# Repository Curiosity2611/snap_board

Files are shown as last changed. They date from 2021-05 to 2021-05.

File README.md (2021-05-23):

## About the project

### Problem

Recently I came accross the ST's line of Microprocessors and I felt it fascinating. I personally felt this is one of the best Microprocessor out there in the market as it is the combination of an MPU and an  MCU. This combination has many use cases and I felt I should try this out. So I bought STM32MP157C-DK2 development board and started experimenting! <br>

Previously I had little experience working on couple of popular linux dev boards like the BeagleBone Black
and the Raspberry Pi. They are both fantastic boards to work with and they both have good community support. But while working with them, I realised a few bunch of problems:

- **Raspberry Pi Compute Module 4 + IO Board**
    - CM4 is easy to use but not ideal for mass production.
    - No support for analog signals at hardware level.
    - Software PWM possible but not very precise.
    - Cannot support real time application or processing.
    - Not fully open-source and very minimum customization possible. <br>
<br>

- **BeagleBone Black**
    - Easy to use but user has to own build hardware for production.
    - PRUs make RT applications possible but super difficult to use.
    - Cannot support MIPI-DSI and HD graphics.
    - Programming PRUs is not an easy task.

### Solution

**Best of both worlds**

**Hello World STM32MP1 !!**

- Board design inspired from Raspberry Pi Compute Module 4 and CM4 IO board.
- Operating system derived from Beaglebone Black with implementation of Bonescript Library and Cloud9 IDE.
- Footprint compatible Single or dual Cortex-A7 Processors + dedicated Cortex-M4 core for real-time and low-power applications.
- Support for MIPI-DSI display for HMI applications.
- Fully open-source Hardware and Software.

## Full Documentation

The full documentation is done using mkdocs tool and is present in the documentation folder. To view the doucmentation:
- Install mkdocs tool in your system.
- `cd` to `documentation/snap_board`
- run the command `mkdocs serve`
- Redirect your browser to `http://127.0.0.1:8000/`

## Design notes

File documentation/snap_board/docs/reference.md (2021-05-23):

# References for STM32MP157C

## Websites
- [STM32MP157C-DK2 official website](https://www.st.com/en/evaluation-tools/stm32mp157c-dk2.html#overview)
- [STM32MP157C Chipset](https://www.st.com/en/microcontrollers-microprocessors/stm32mp157c.html)

## Docs
- STM32MP157C-DK2 Development Board:

    - [Data Brief (PDF)](https://www.st.com/resource/en/data_brief/stm32mp157c-dk2.pdf)
    - [User Manual UM2534 (PDF)](https://www.st.com/resource/en/user_manual/dm00591354-discovery-kits-with-stm32mp157-mpus-stmicroelectronics.pdf)

- MPU:
    - [STM32MP157C DataSheet DS12505(PDF)](https://www.st.com/resource/en/datasheet/stm32mp157c.pdf)
    - [Reference Manual RM0436 (PDF)](https://www.st.com/resource/en/reference_manual/dm00327659-stm32mp157-advanced-armbased-32bit-mpus-stmicroelectronics.pdf)

- PMIC:
    - [STPMIC1 Datasheet (PDF)](https://www.mouser.in/datasheet/2/389/dm00551687-1799430.pdf)

- DDR3L:
    - [AS4C256M16D3LC-12BCN Datasheet (PDF)](https://www.mouser.in/datasheet/2/12/AllianceMemory_4G_DDR3L_AS4C256M16D3LC_March2020_R-1826861.pdf)

- eMMC:
    - [S40FC004C1B2C00000 Datasheet (PDF)](https://www.mouser.in/datasheet/2/980/SkyHigh_Memory_4GB_153_ball_VFBGA_eMMC_5.1_Data_Sh-1812167.pdf)

## CAD
- Board Manufacturing:

    - [Board Design Project Files 1.0 MB1272](https://www.st.com/resource/en/board_manufacturing_specification/mb1272_bdp.zip)
    - [Board Manufacturing Files 1.0 MB1272](https://www.st.com/resource/en/board_manufacturing_specification/mb1272_manufacturing.zip)

- Bill of Materials:

    - [BOM MB1272](https://www.st.com/resource/en/bill_of_materials/mb1272_bom.zip)
- Schematics:
    - [Schematic MB1272 (PDF)](https://www.st.com/resource/en/schematic_pack/mb1272-dk2-c01_schematic.pdf)

## Application Notes

- [Getting started with STM32MP15x Hardware Development AN5031](https://www.st.com/resource/en/application_note/dm00389996-getting-started-with-stm32mp151-stm32mp153-and-stm32mp157-line-hardware-development-stmicroelectronics.pdf)
- [STM31MP1 series DDR Memory routing guidelines AN5122](https://www.st.com/resource/en/application_note/dm00462392-stm32mp1-series-ddr-memory-routing-guidelines-stmicroelectronics.pdf)
- [Oscillator design guide for STM32MP15x AN2867](https://www.st.com/resource/en/application_note/cd00221665-oscillator-design-guide-for-stm8afals-stm32-mcus-and-mpus-stmicroelectronics.pdf)
- [Discrete Power supply hardware integration AN5256](https://www.st.com/resource/en/application_note/dm00561921-stm32mp151-stm32mp153-and-stm32mp157-discrete-power-supply-hardware-integration-stmicroelectronics.pdf)
- [USB-C power delivery AN5225](https://www.st.com/resource/en/application_note/dm00536349-usb-typec-power-delivery-using-stm32-mcus-and-mpus-stmicroelectronics.pdf)

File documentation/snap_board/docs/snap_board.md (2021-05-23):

## Hardware Development

### Introduction

Minimum hardware resources and recommendations provided by ST on how to use STM32MP151, STM32MP153 and STM32MP157 lines of MPUs. Refer Application note [Getting started with STM32MP15x Hardware Development AN5031](https://www.st.com/resource/en/application_note/dm00389996-getting-started-with-stm32mp151-stm32mp153-and-stm32mp157-line-hardware-development-stmicroelectronics.pdf) for more detailed information.

### Package Selection

A package is selected by taking into account the following constraints:

- Amount of interfaces required as some interfaces might not be available on some packages and some interfaces combinations might not be possible on some packages.
- PCB available area and PCB technology constraints. Small pitch and high ball density could require more PCB layers and higher PCB class requiring stackup with micro-via (laser via) technology.
- Package size and ball pitch.
- Cost of the MPU.

**Manufacturer Part Number** - STM32MP157CAC3 / STM32MP151CAC3 <br>
**Package** -  TFBGA361 <br>
**Package Size** - 12mm x 12mm. <br>
**Minimum Pitch** - 0.5mm (Center 0.65) <br>
**Thickness** - < 1.2mm. <br>
**Ball Count** - 361 <br>

### Power Supplies

#### General

The system is supplied with 12V DC power supply through a barrel jack connector present on the IO board. This 12V is step down to 5V using a buck converter on the I/O board and is supplied to the PMIC. <br>

**Schematic Name Tag for 5V supply** - `5V_VIN` <br>

#### ST PMIC Overview

**Manfacturer Part Number** - STPMIC1BPQR <br>
**Package** - WFQFN 44L <br>
**Package Dimesion** - 5mm x 6mm x 0.8mm <br>

!!! note
    The STPMIC1A and STPMIC1B are pre-programmed devices to support the STM32MP1 series application processor versions. 

The STPMIC1 provides all regulators needed to power supply a complete application. This IC is preset on Snap board. It has:

- 6 LDOs + 1 reference voltage LDO for DDR Memories. 
- 4 Step down (buck) converter. 
- 1 step-up(boost) converter with a bypass to supply USB sub-system.
- 2 power switches to supply USB sub-system. 

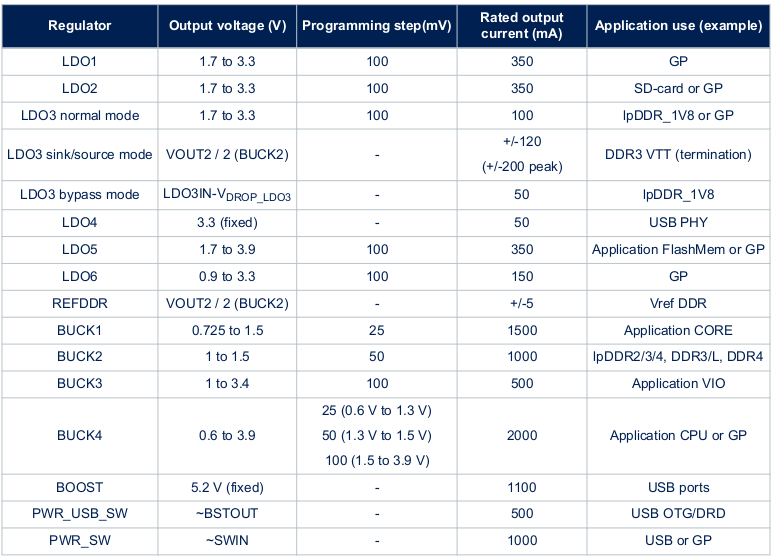
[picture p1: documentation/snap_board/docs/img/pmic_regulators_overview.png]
PMIC regulators overview


**LDO1, LDO2, LDO5, LDO6** are general purpose (GP) LDO (low-dropout) linear regulators and can be used to supply application peripherals. <br>

**LDO3** is a multipurpose linear regulator that supports 3 modes:

- **Normal mode**: operates as standard LDO with 1.7 to 3.3 V output voltage range (for general purpose use)
- **Sink/source mode**: LDO3 operates in sink/source regulation mode to supply termination resistors of DDR3/DDR3L memory interface (VTT voltage).
- **Bypass mode**: LDO3 operates as a simple power switch to supply lpDDR2/3 VDD1 (1.8 V) power domain. In that case, LDO3IN is supplied by 1.8 V. This is a preferred mode versus normal mode in term of power efficiency to power supply lpDDR2/3 VDD1.

!!! note
    In this application LDO3 is used as Sink/Source mode.

**LDO4** is a fixed output voltage (3.3 V) LDO and it is dedicated to power supply host processor USB PHY. <br>

**DDR REF** is sink/source reference voltage LDO dedicated to power VREF of lpDDR/DDR.<br>

**BOOST** is a fixed output voltage 5.2 V synchronous step-up converter dedicated to power supply USB ports (PWR_USB_SW and/or PWR_SW power switches).

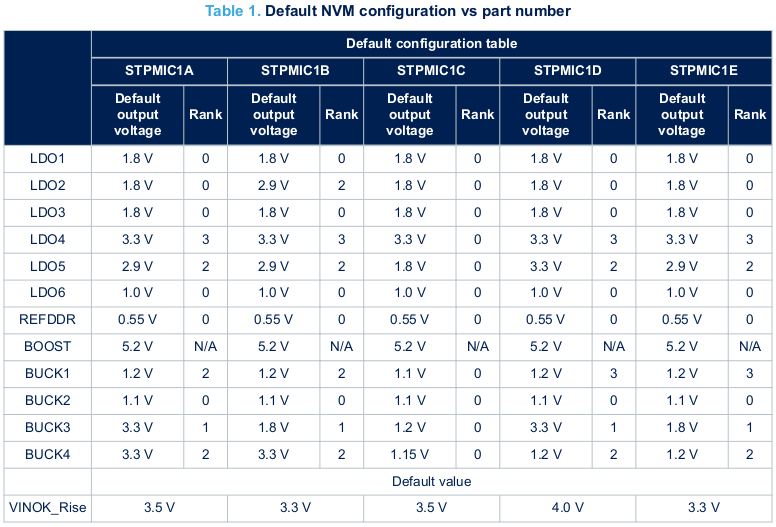
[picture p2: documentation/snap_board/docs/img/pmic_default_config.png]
PMIC Default Configuration


#### LDO Typical Schematic

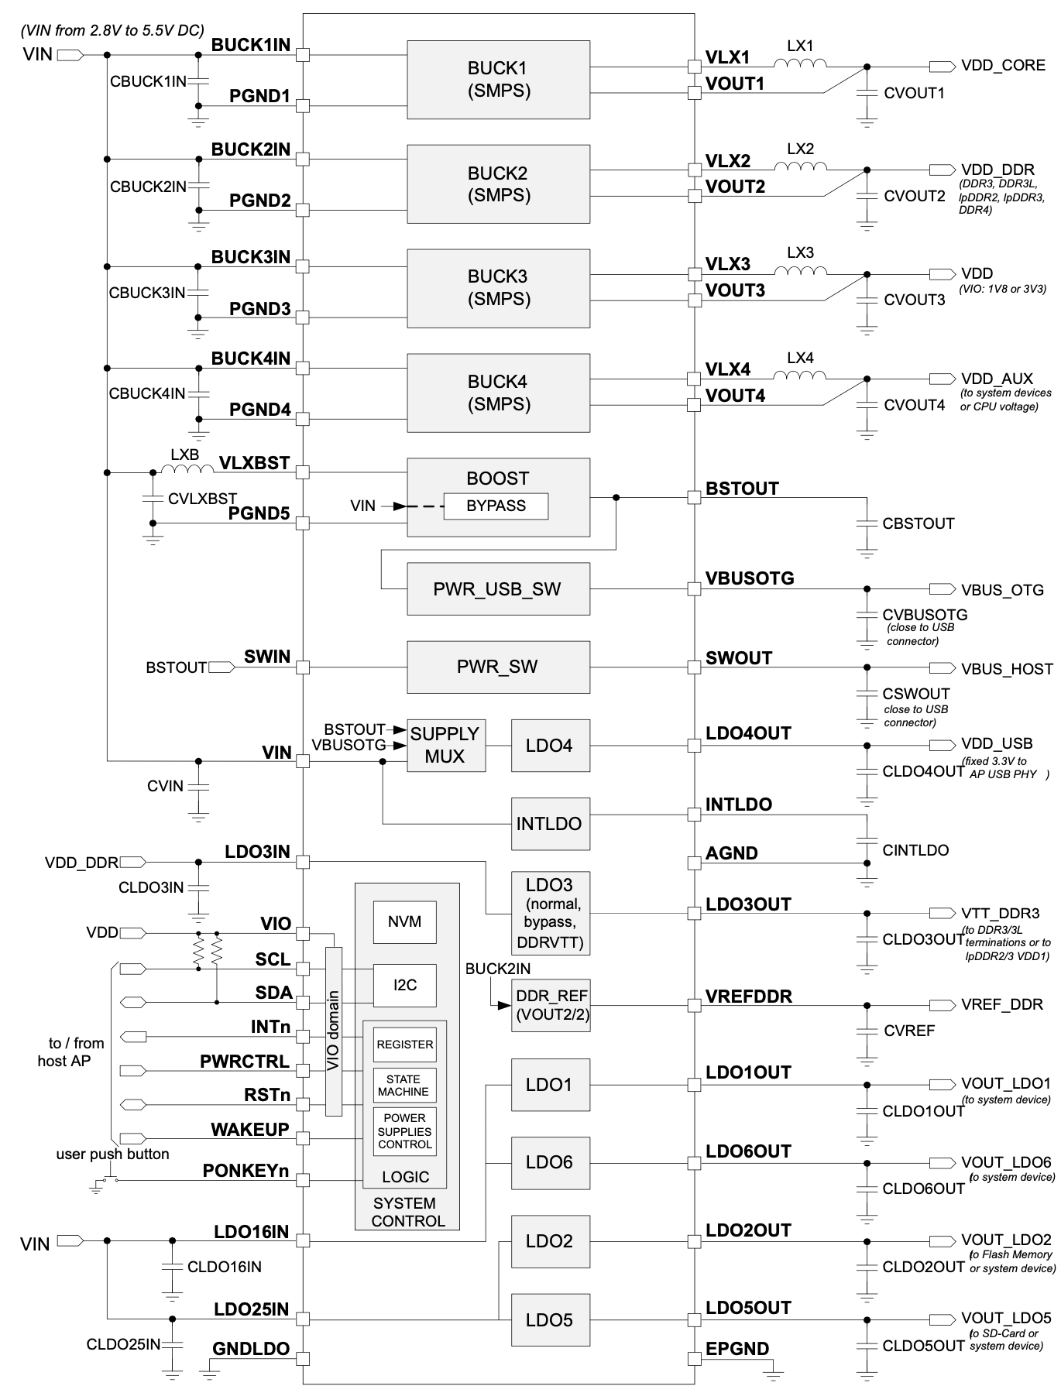
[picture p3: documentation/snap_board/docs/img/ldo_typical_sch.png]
Typical LDO Schematic


#### Powering DDR3 Memory with STPMIC

In this project, DDR3L memory is used. 

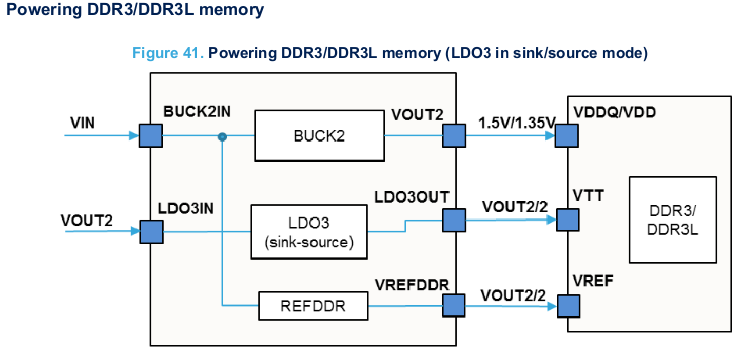
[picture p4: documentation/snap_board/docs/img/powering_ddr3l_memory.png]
Powering DDR3L Memory


LDO3IN is a power supply from BUCK2 output (VOUT2) and LDO3 output regulate at Vout2/2 voltage.

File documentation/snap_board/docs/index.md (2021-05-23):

# The Snap Project

### Problem

Recently I came accross the ST's line of Microprocessors and I felt it fascinating. I personally felt this is one of the best Microprocessor out there in the market as it is the combination of an MPU and an  MCU. This combination has many use cases and I felt I should try this out. So I bought STM32MP157C-DK2 development board and started experimenting! <br>

Previously I had little experience working on couple of popular linux dev boards like the BeagleBone Black
and the Raspberry Pi. They are both fantastic boards to work with and they both have good community support. But while working with them, I realised a few bunch of problems:

- **Raspberry Pi Compute Module 4 + IO Board**
    - CM4 is easy to use but not ideal for mass production.
    - No support for analog signals at hardware level.
    - Software PWM possible but not very precise.
    - Cannot support real time application or processing.
    - Not fully open-source and very minimum customization possible. <br>
<br>

- **BeagleBone Black**
    - Easy to use but user has to own build hardware for production.
    - PRUs make RT applications possible but super difficult to use.
    - Cannot support MIPI-DSI and HD graphics.
    - Programming PRUs is not an easy task.

### Solution

**Best of both worlds**

**Hello World STM32MP1 !!**

- Board design inspired from Raspberry Pi Compute Module 4 and CM4 IO board.
- Operating system derived from Beaglebone Black with implementation of Bonescript Library and Cloud9 IDE.
- Footprint compatible Single or dual Cortex-A7 Processors + dedicated Cortex-M4 core for real-time and low-power applications.
- Support for MIPI-DSI display for HMI applications.
- Fully open-source Hardware and Software.

This documentation is on design notes/decisions used to develop snap developement boards. This documentation will be updated from time to time based on new learnings and as the project progresses. This Wiki is designed to consolidate my knowledge into a one stop source for future refereces. That said, this Wiki is:

- Not exhaustive. 
- Constantly being updated with new information. 
- May contain some errors (will be corrected if found!)

### About Me!

My name is Deepak Reddy and I maintain this documentation. I hold an undergraduate degree in Electrical and Electronics Engineering and I worked as a Hardware Design Engineer for 4 years in a startup. During my time in the company, I developed various products that went from concept to production. I have designed PCBs arounds various SoCs such as 8-bit MCUs, and 32-bit MCUs. I have also designed rigid-flex and HDI PCBs.

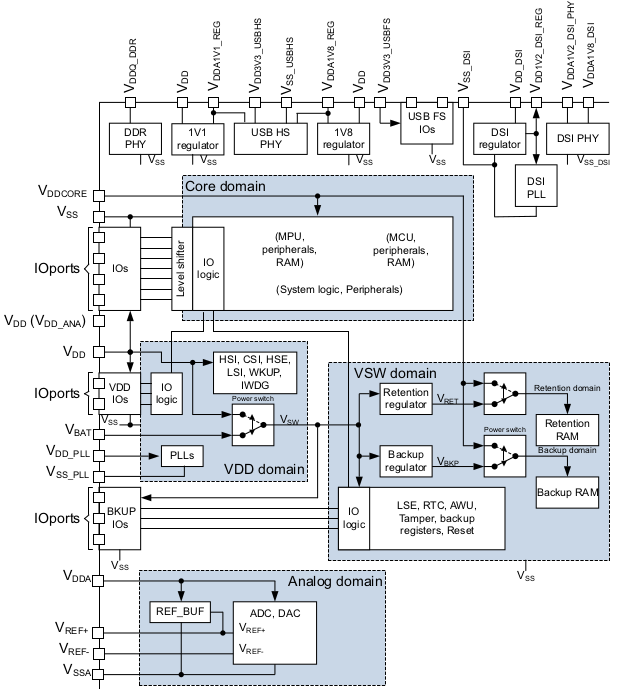
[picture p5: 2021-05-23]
documentation/snap_board/docs/img/power_supply_scheme.png

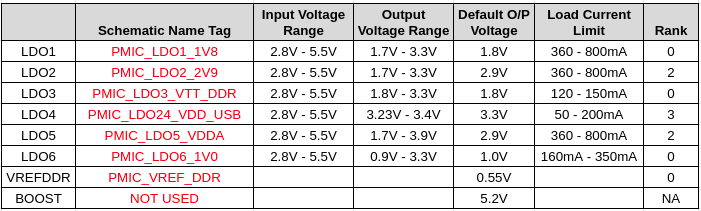
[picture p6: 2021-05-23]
documentation/snap_board/docs/img/ldo_voltages.png

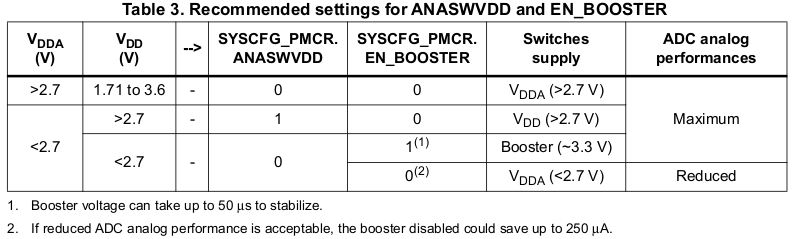
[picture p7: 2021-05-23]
documentation/snap_board/docs/img/ADC_SYSCFG_settings.png

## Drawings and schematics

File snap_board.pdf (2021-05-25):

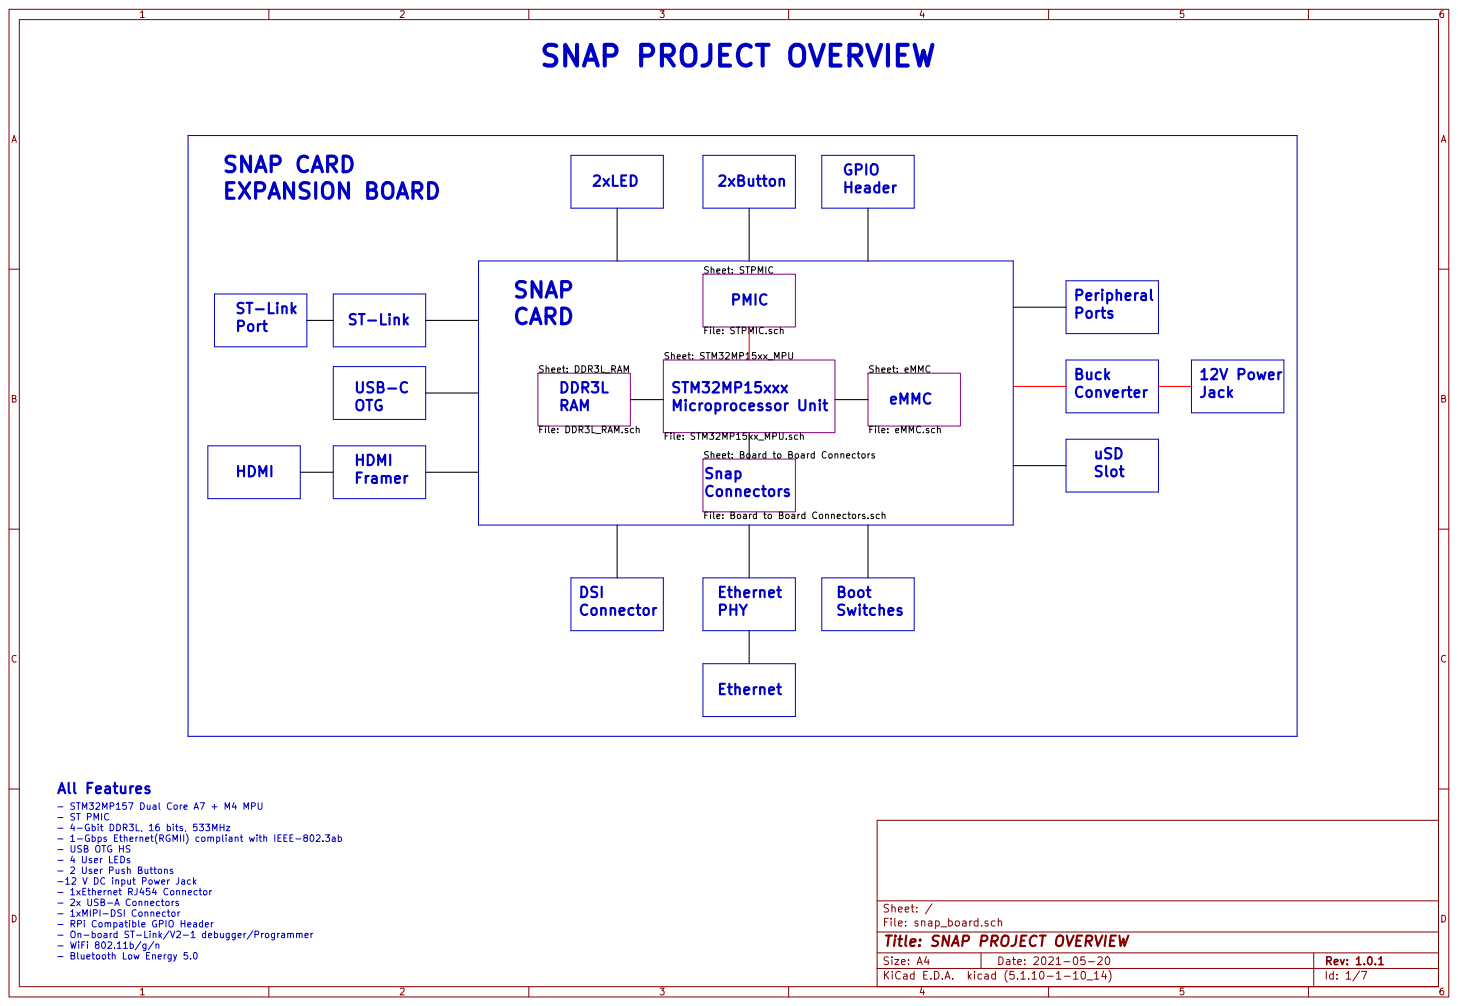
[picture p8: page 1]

Sheet: Board to Board Connectors File: Board to Board Connectors.sch Sheet: STPMIC
PMIC

- STM32MP157 Dual Core A7 + M4 MPU
- ST PMIC
- 4-Gbit DDR3L, 16 bits, 533MHz
- 1-Gbps Ethernet(RGMII) compliant with IEEE-802.3ab
- USB OTG HS
- 4 User LEDs
- 2 User Push Buttons
-12 V DC input Power Jack
- 1xEthernet RJ454 Connector
- 2x USB-A Connectors
- 1xMIPI-DSI Connector
- RPi Compatible GPIO Header
- On-board ST-Link/V2-1 debugger/Programmer
- WiFi 802.11b/g/n
- Bluetooth Low Energy 5.0

File: snap_board.sch Sheet: /
Id: 1/7 Title: SNAP PROJECT OVERVIEW

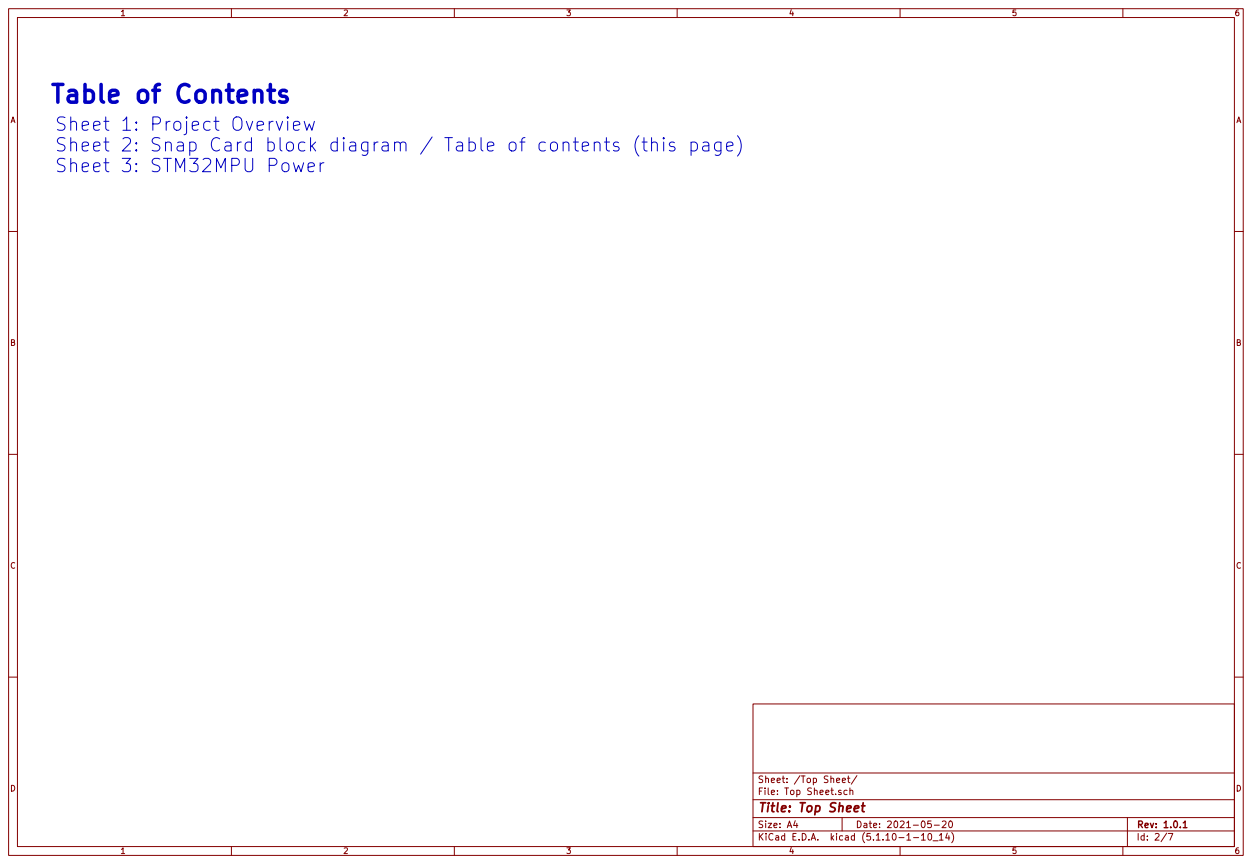
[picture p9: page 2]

Table of Contents
Sheet 1: Project Overview
Sheet 2: Snap Card block diagram / Table of contents (this page)
Sheet 3: STM32MPU Power

Sheet: /Top Sheet/
File: Top Sheet.sch
Id: 2/7 Title: Top Sheet

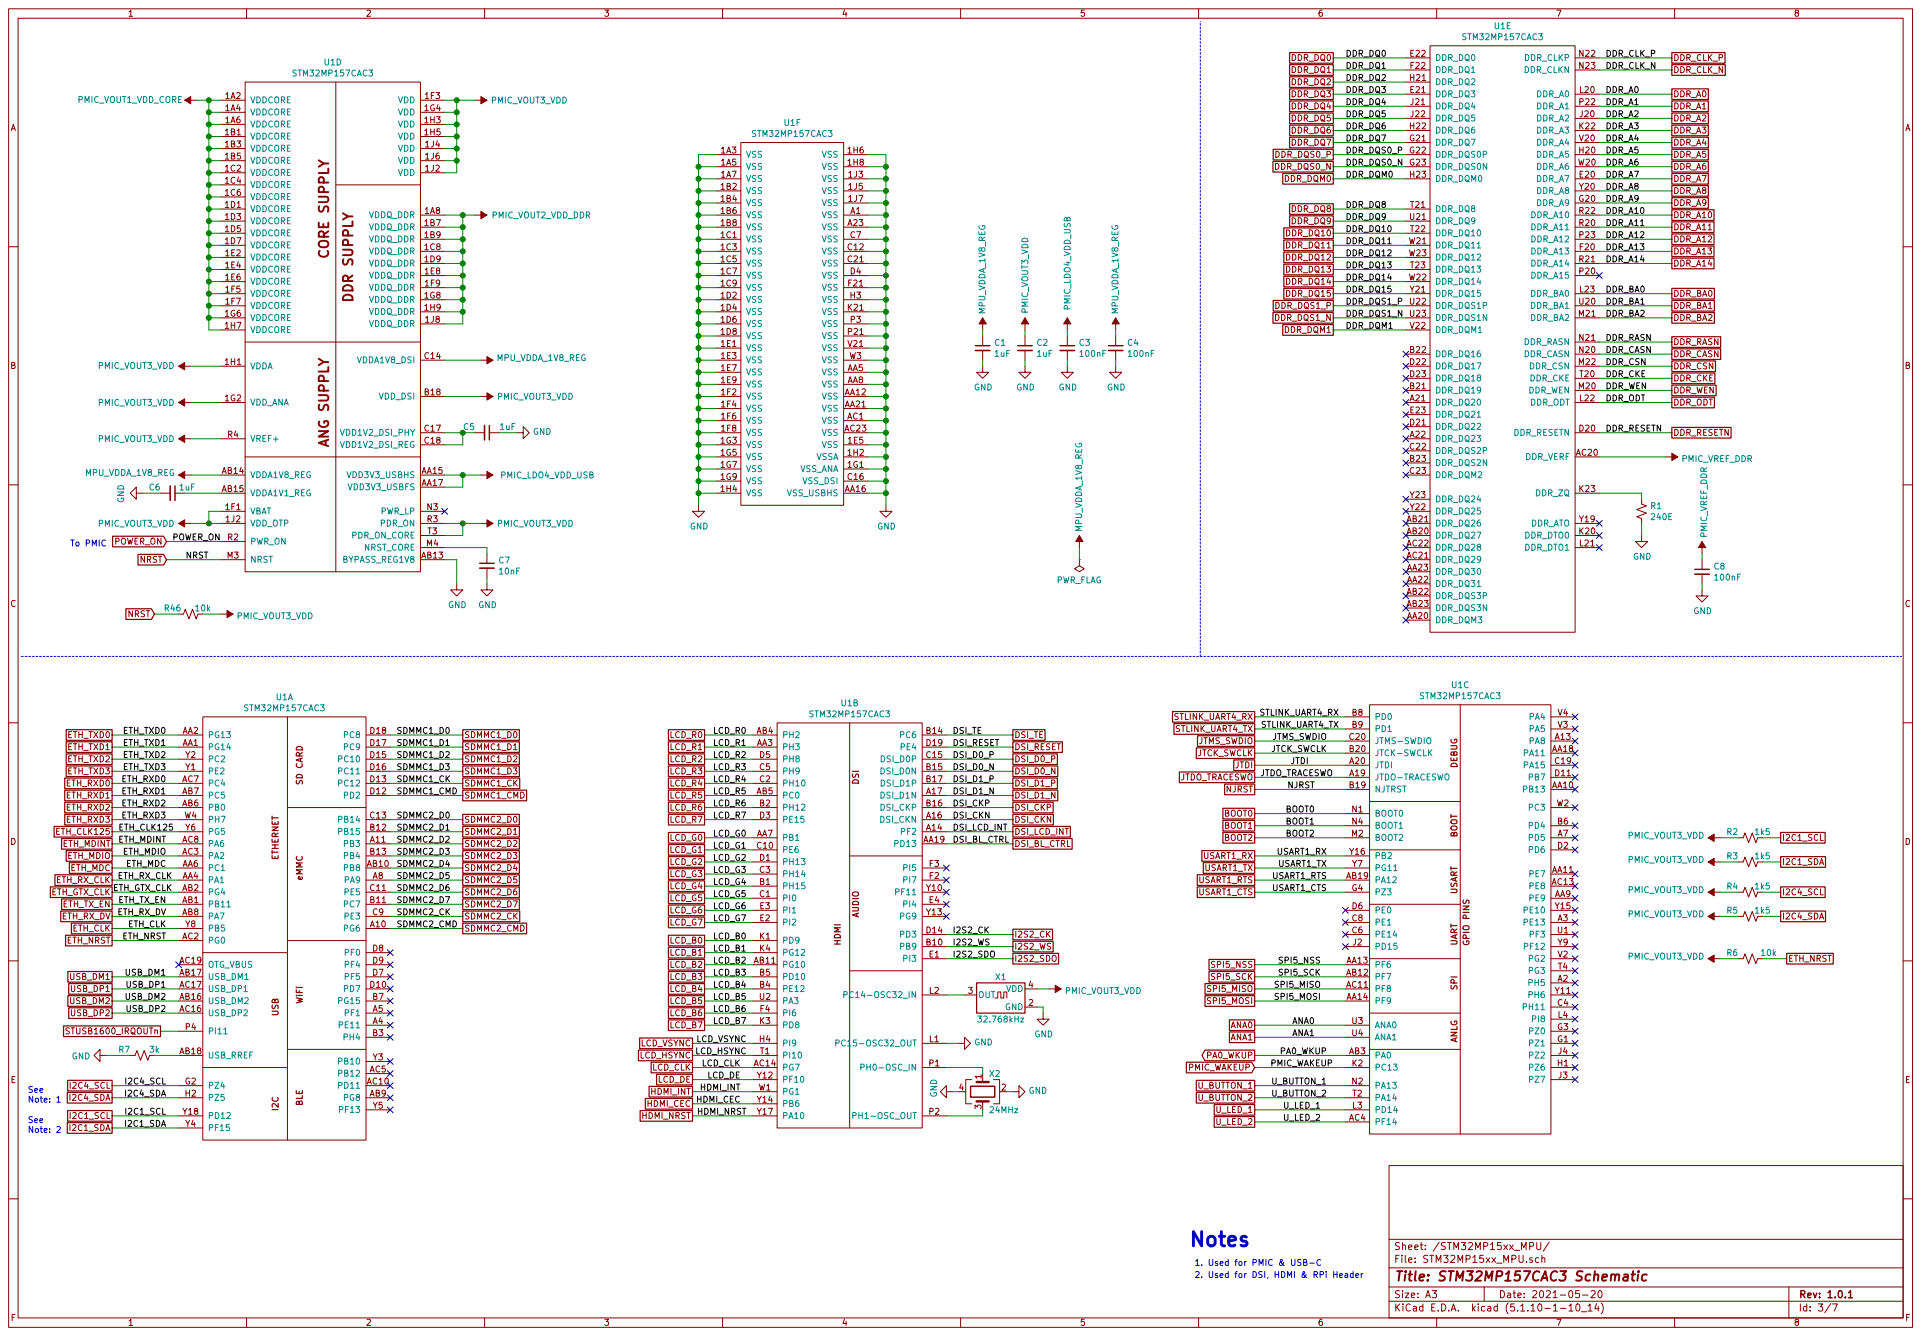
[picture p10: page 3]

ETH_RXD3 ETH_CLK125 ETH_RXD2 ETH_TXD3 ETH_RXD0 ETH_RXD1 See Note: 1 See Note: 2

1. Used for PMIC & USB-C
2. Used for DSI, HDMI & RPi Header

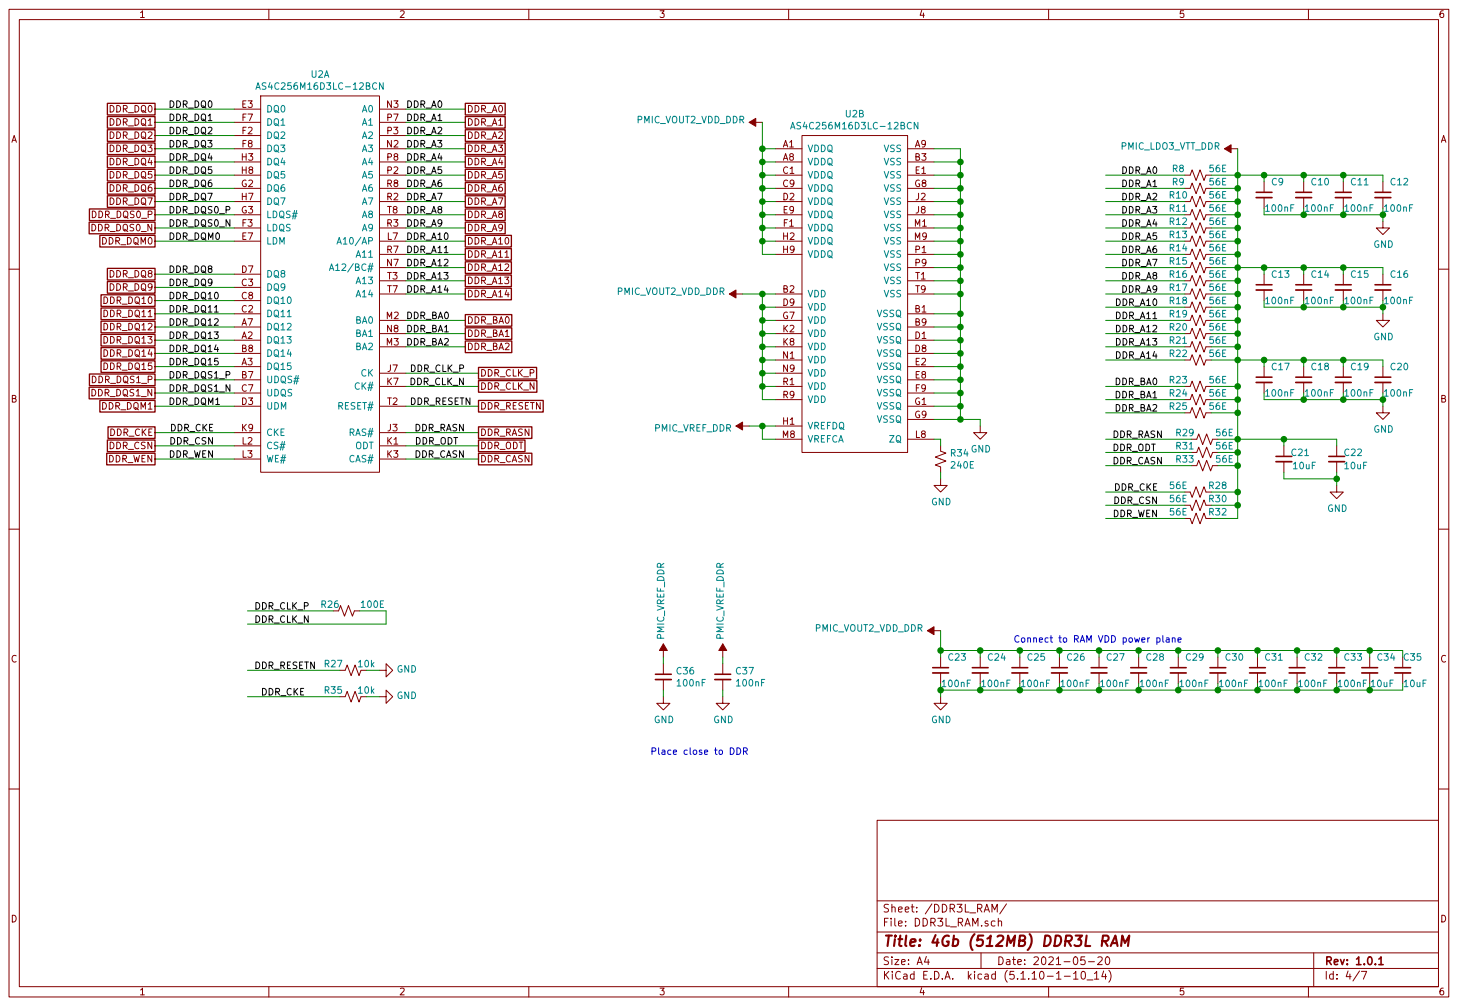
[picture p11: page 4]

DDR_CKE DDR_A2 DDR_A3 DDR_A4 DDR_A5 DDR_A6 DDR_A7 DDR_A8 DDR_A9 DDR_A10 DDR_A11 DDR_A12 DDR_A13 DDR_A14 DDR_BA0 Connect to RAM VDD power plane Place close to DDR

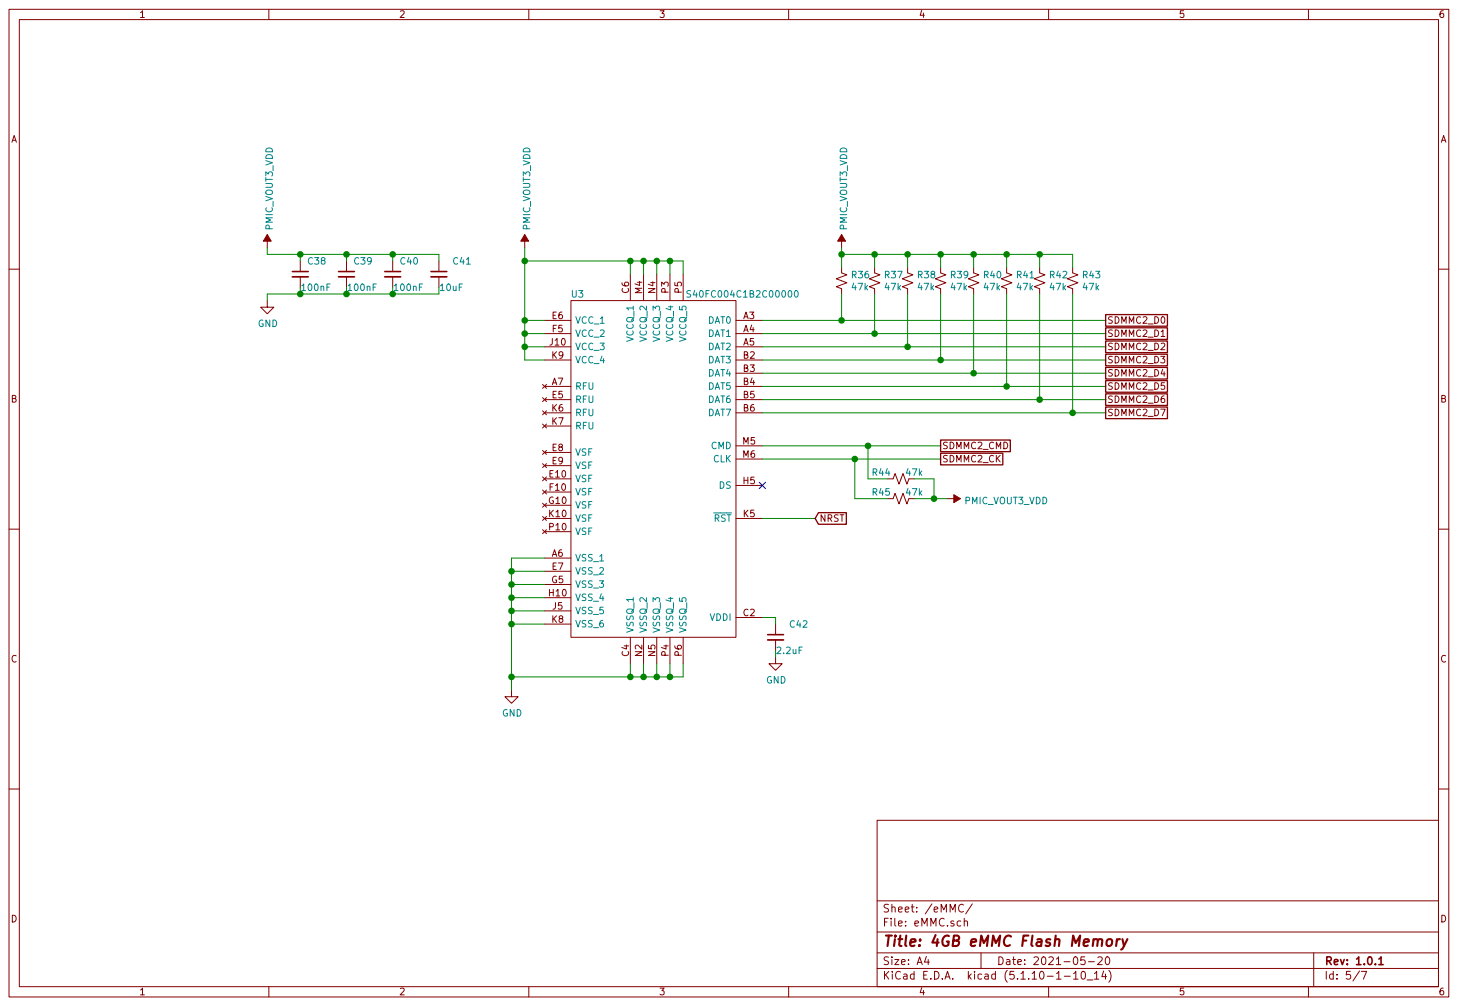
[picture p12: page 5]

Id: 5/7 Title: 4GB eMMC Flash Memory

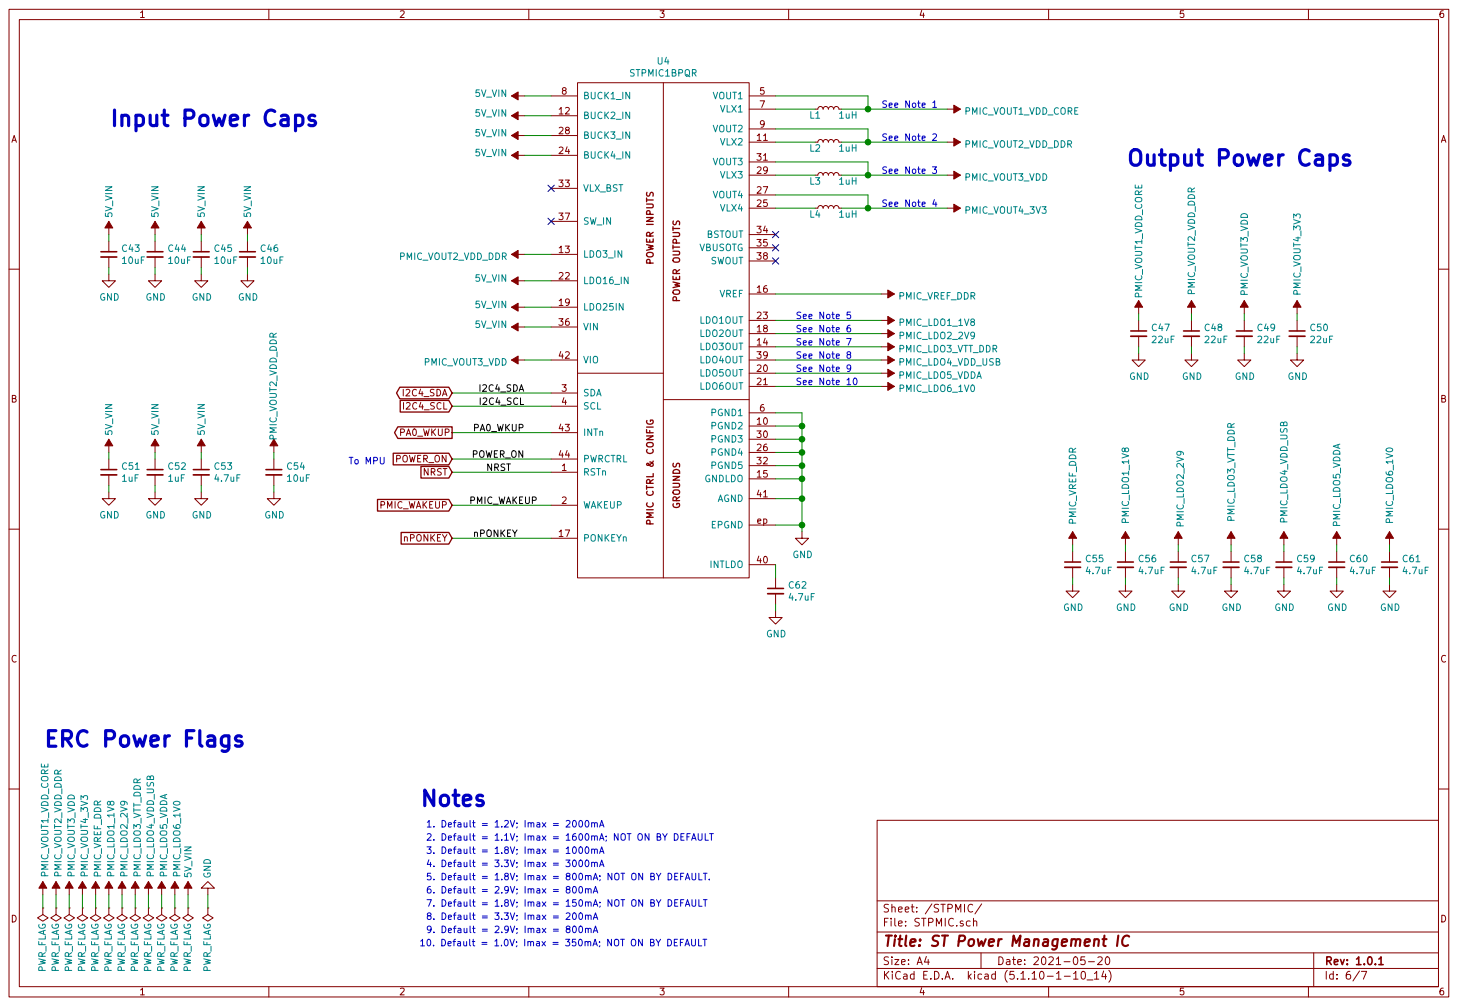
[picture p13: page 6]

4. Default = 3.3V; Imax = 3000mA ERC Power Flags

5. Default = 1.8V; Imax = 800mA; NOT ON BY DEFAULT. Notes

1. Default = 1.2V; Imax = 2000mA
2. Default = 1.1V; Imax = 1600mA; NOT ON BY DEFAULT
3. Default = 1.8V; Imax = 1000mA

6. Default = 2.9V; Imax = 800mA
7. Default = 1.8V; Imax = 150mA; NOT ON BY DEFAULT
8. Default = 3.3V; Imax = 200mA
9. Default = 2.9V; Imax = 800mA
10. Default = 1.0V; Imax = 350mA; NOT ON BY DEFAULT

Id: 6/7 Title: ST Power Management IC

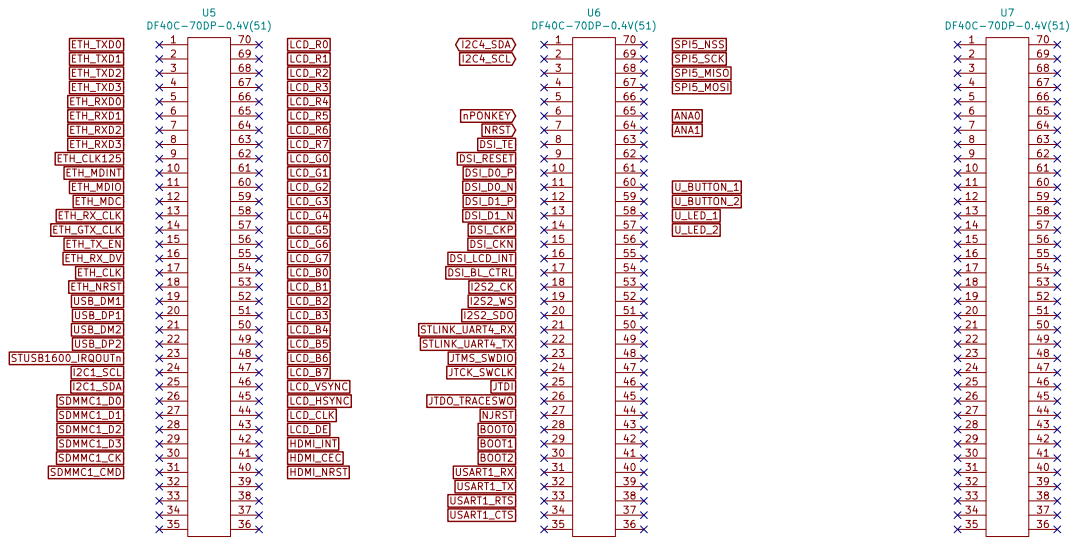
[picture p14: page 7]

File: Board to Board Connectors.sch Sheet: /Board to Board Connectors/
Id: 7/7 Title: Board to Board Snap Connectors

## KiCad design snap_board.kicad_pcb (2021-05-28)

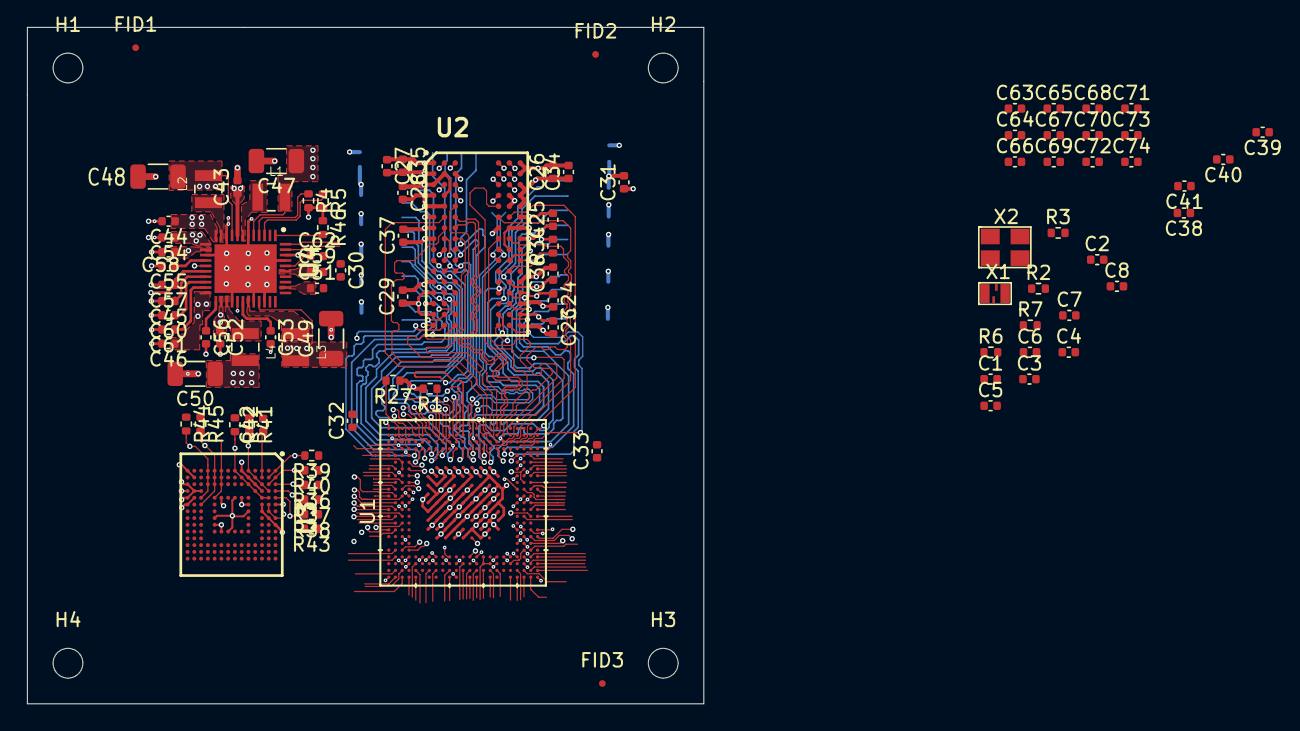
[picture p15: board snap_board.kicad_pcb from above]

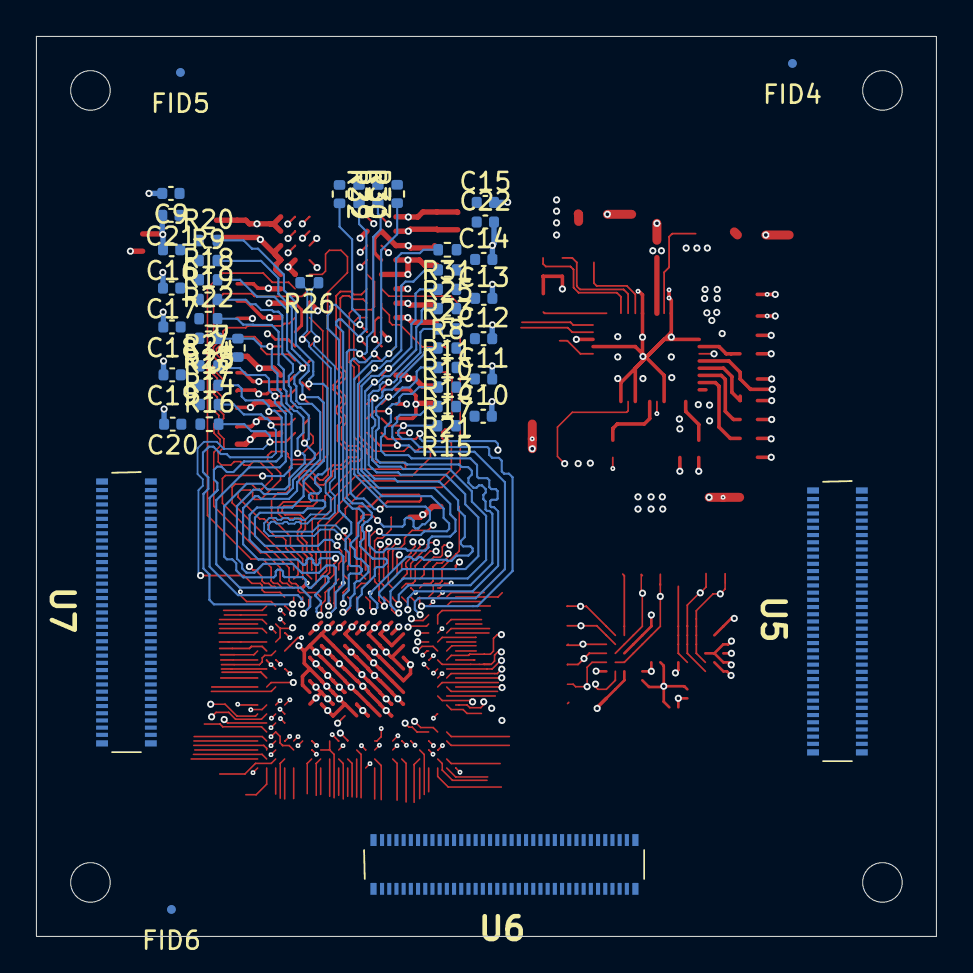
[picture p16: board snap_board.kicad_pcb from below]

Board: 6 copper layers, 50.0 x 50.0 mm, 143 parts (46 on the bottom side), 97 nets.

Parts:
C1, C2, C5, C6, C51, C52, C63, C64, C65, C66, C67, C68, C69, C70, C71, C72, C73, C74: 1uF; C_0402_1005Metric
C3, C4, C8, C9, C10, C11, C12, C13, C14, C15, C16, C17, C18, C19, C20, C23, C24, C25, C26, C27, C28, C29, C30, C31, C32, C33, C36, C37, C38, C39, C40: 100nF; C_0402_1005Metric
C7: 10nF; C_0402_1005Metric
C21, C22, C34, C35, C41, C43, C44, C45, C46, C54: 10uF; C_0402_1005Metric
C42: 2.2uF; C_0402_1005Metric
C47, C48, C49, C50: 22uF; C_1206_3216Metric
C53, C55, C56, C57, C58, C59, C60, C61, C62: 4.7uF; C_0402_1005Metric
FID1, FID2, FID3, FID4, FID5, FID6: Fiducial; Fiducial_0.5mm_Mask1.5mm
H1, H2, H3, H4: MountingHole_Pad; MountingHole_2.2mm_M2
L1, L2, L3, L4: 1uH; MGV2520101R0M-10
R1, R34: 240E; R_0402_1005Metric
R2, R3, R4, R5: 1k5; R_0402_1005Metric
R6, R27, R35, R46: 10k; R_0402_1005Metric
R7: 3k; R_0402_1005Metric
R8, R9, R10, R11, R12, R13, R14, R15, R16, R17, R18, R19, R20, R21, R22, R23, R24, R25, R28, R29, R30, R31, R32, R33: 56E; R_0402_1005Metric
R26: 100E; R_0402_1005Metric
R36, R37, R38, R39, R40, R41, R42, R43, R44, R45: 47k; R_0402_1005Metric
U1: STM32MP157CAC3
U2: AS4C256M16D3LC-12BCN
U3: S40FC004C1B2C00000
U4: STPMIC1BPQR
U5, U6, U7: DF40C-70DP-0.4V(51); DF40C70DP04V51
X1: 32.768kHz; SiT1533AC-H5-DCC-32.768E
X2: 24MHz; TSX3225240000MF10ZC3

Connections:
5V_VIN: C43.1, C44.1, C45.1, C46.1, C51.1, C52.1, C53.1, U4.8, U4.12, U4.19, U4.22, U4.24, U4.28, U4.36
DDR_A0: R8.2, U1.L20, U2.N3
DDR_A1: R9.2, U1.P22, U2.P7
DDR_A2: R10.2, U1.J20, U2.P3
DDR_A3: R11.2, U1.K22, U2.N2
DDR_A4: R12.2, U1.V20, U2.P8
DDR_A5: R13.2, U1.H20, U2.P2
DDR_A6: R14.2, U1.W20, U2.R8
DDR_A7: R15.2, U1.E20, U2.R2
DDR_A8: R16.2, U1.Y20, U2.T8
DDR_A9: R17.2, U1.G20, U2.R3
DDR_A10: R18.2, U1.R22, U2.L7
DDR_A11: R19.2, U1.R20, U2.R7
DDR_A12: R20.2, U1.P23, U2.N7
DDR_A13: R21.2, U1.F20, U2.T3
DDR_A14: R22.2, U1.R21, U2.T7
DDR_BA0: R23.2, U1.L23, U2.M2
DDR_BA1: R24.2, U1.U20, U2.N8
DDR_BA2: R25.2, U1.M21, U2.M3
DDR_CASN: R33.2, U1.N20, U2.K3
DDR_CKE: R28.1, R35.2, U1.T20, U2.K9
DDR_CLK_N: R26.1, U1.N23, U2.K7
DDR_CLK_P: R26.2, U1.N22, U2.J7
DDR_CSN: R30.1, U1.M22, U2.L2
DDR_DQ0: U1.E22, U2.A2
DDR_DQ1: U1.F22, U2.C3
DDR_DQ2: U1.H21, U2.A7
DDR_DQ3: U1.E21, U2.C2
DDR_DQ4: U1.J21, U2.B8
DDR_DQ5: U1.J22, U2.C8
DDR_DQ6: U1.H22, U2.D7
DDR_DQ7: U1.G21, U2.A3
DDR_DQ8: U1.T21, U2.F2
DDR_DQ9: U1.U21, U2.E3
DDR_DQ10: U1.T22, U2.G2
DDR_DQ11: U1.W21, U2.F7
DDR_DQ12: U1.W23, U2.H8
DDR_DQ13: U1.T23, U2.H3
DDR_DQ14: U1.W22, U2.H7
DDR_DQ15: U1.Y21, U2.F8
DDR_DQM0: U1.H23, U2.D3
DDR_DQM1: U1.V22, U2.E7
DDR_DQS0_N: U1.G23, U2.B7
DDR_DQS0_P: U1.G22, U2.C7
DDR_DQS1_N: U1.U23, U2.G3
DDR_DQS1_P: U1.U22, U2.F3
DDR_ODT: R31.2, U1.L22, U2.K1
DDR_RASN: R29.2, U1.N21, U2.J3
DDR_RESETN: R27.2, U1.D20, U2.T2
DDR_WEN: R32.1, U1.M20, U2.L3
ETH_NRST: R6.1, U1.AC2
GND: C1.2, C2.2, C3.2, C4.2, C5.1, C6.2, C7.2, C8.2, C9.2, C10.2, C11.2, C12.2, C13.2, C14.2, C15.2, C16.2, C17.2, C18.2, C19.2, C20.2, C21.2, C22.2, C23.2, C24.2, C25.2, C26.2, C27.2, C28.2, C29.2, C30.2, C31.2, C32.2, C33.2, C34.2, C35.2, C36.2, C37.2, C38.2, C39.2, C40.2, C41.2, C42.2, C43.2, C44.2, C45.2, C46.2, C47.2, C48.2, C49.2, C50.2, C51.2, C52.2, C53.2, C54.2, C55.2, C56.2, C57.2, C58.2, C59.2, C60.2, C61.2, C62.2, C63.2, C64.2, C65.2, C66.2, C67.2, C68.2, C69.2, C70.2, C71.2, C72.2, C73.2, C74.2, R1.2, R7.2, R27.1, R34.2, R35.1, U1.1A3, U1.1A5, U1.1A7, U1.1B2, U1.1B4, U1.1B6, U1.1B8, U1.1C1, U1.1C3, U1.1C5, U1.1C7, U1.1C9, U1.1D2, U1.1D4, U1.1D6, U1.1D8, U1.1E1, U1.1E3, U1.1E5, U1.1E7, U1.1E9, U1.1F2, U1.1F4, U1.1F6, U1.1F8, U1.1G1, U1.1G3, U1.1G5, U1.1G7, U1.1G9, U1.1H2, U1.1H4, U1.1H6, U1.1H8, U1.1J3, U1.1J5, U1.1J7, U1.A1, U1.A23, U1.AA5, U1.AA8, U1.AA12, U1.AA16, U1.AA21, U1.AB13, U1.AC1, U1.AC23, U1.C7, U1.C12, U1.C16, U1.C21, U1.D4, U1.F21, U1.H3, U1.K21, U1.L1, U1.P3, U1.P21, U1.V21, U1.W3, U2.A9, U2.B1, U2.B3, U2.B9, U2.D1, U2.D8, U2.E1, U2.E2, U2.E8, U2.F9, U2.G1, U2.G8, U2.G9, U2.J2, U2.J8, U2.M1, U2.M9, U2.P1, U2.P9, U2.T1, U2.T9, U3.A6, U3.C4, U3.D3, U3.E2, U3.E7, U3.F1, U3.G5, U3.H10, U3.J5, U3.K8, U3.N2, U3.N5, U3.P1, U3.P4, U3.P6, U4.6, U4.10, U4.15, U4.26, U4.30, U4.32, U4.41, U4.ep, X1.2, X2.2, X2.4
I2C1_SCL: R2.1, U1.Y18
I2C1_SDA: R3.1, U1.Y4
I2C4_SCL: R4.1, U1.G2, U4.4
I2C4_SDA: R5.1, U1.H2, U4.3
MPU_VDDA_1V8_REG: C1.1, C4.1, U1.AB14, U1.C14
NRST: R46.2, U1.M3, U3.J1, U3.J2, U3.J3, U3.K5, U4.1
unnamed: C5.2, U1.C17, U1.C18
unnamed: C6.1, U1.AB15
unnamed: C7.1, U1.M4
unnamed: C42.1, U3.C1, U3.C2
unnamed: C62.1, U4.40
unnamed: L1.1, U4.7
unnamed: L2.1, U4.11
unnamed: L3.1, U4.29
unnamed: L4.1, U4.25
unnamed: R1.1, U1.K23
unnamed: R7.1, U1.AB18
unnamed: R34.1, U2.L8
unnamed: U1.L2, X1.3
unnamed: U1.P1, X2.1
unnamed: U1.P2, X2.3
PA0_WKUP: U1.AB3, U4.43
PMIC_LDO1_1V8: C56.1, U4.23
PMIC_LDO2_2V9: C57.1, U4.18
PMIC_LDO3_VTT_DDR: C9.1, C10.1, C11.1, C12.1, C13.1, C14.1, C15.1, C16.1, C17.1, C18.1, C19.1, C20.1, C21.1, C22.1, C58.1, R8.1, R9.1, R10.1, R11.1, R12.1, R13.1, R14.1, R15.1, R16.1, R17.1, R18.1, R19.1, R20.1, R21.1, R22.1, R23.1, R24.1, R25.1, R28.2, R29.1, R30.2, R31.1, R32.2, R33.1, U4.14
PMIC_LDO4_VDD_USB: C3.1, C59.1, U1.AA15, U1.AA17, U4.39
PMIC_LDO5: C60.1, U4.20
PMIC_LDO6_1V0: C61.1, U4.21
PMIC_VOUT1_VDD_CORE: C47.1, C63.1, C64.1, C65.1, C66.1, L1.2, U1.1A2, U1.1A4, U1.1A6, U1.1B1, U1.1B3, U1.1B5, U1.1C2, U1.1C4, U1.1C6, U1.1D1, U1.1D3, U1.1D5, U1.1D7, U1.1E2, U1.1E4, U1.1E6, U1.1F5, U1.1F7, U1.1G6, U1.1H7, U4.5
PMIC_VOUT2_VDD_DDR: C23.1, C24.1, C25.1, C26.1, C27.1, C28.1, C29.1, C30.1, C31.1, C32.1, C33.1, C34.1, C35.1, C48.1, C54.1, C71.1, C72.1, C73.1, C74.1, L2.2, U1.1A8, U1.1B7, U1.1B9, U1.1C8, U1.1D9, U1.1E8, U1.1F9, U1.1G8, U1.1H9, U1.1J8, U2.A1, U2.A8, U2.B2, U2.C1, U2.C9, U2.D2, U2.D9, U2.E9, U2.F1, U2.G7, U2.H2, U2.H9, U2.K2, U2.K8, U2.N1, U2.N9, U2.R1, U2.R9, U4.9, U4.13
PMIC_VOUT3_VDD: C2.1, C38.1, C39.1, C40.1, C41.1, C49.1, C67.1, C68.1, C69.1, C70.1, L3.2, R2.2, R3.2, R4.2, R5.2, R6.2, R36.1, R37.1, R38.1, R39.1, R40.1, R41.1, R42.1, R43.1, R44.1, R45.1, R46.1, U1.1F1, U1.1F3, U1.1G2, U1.1G4, U1.1H1, U1.1H3, U1.1H5, U1.1J2, U1.1J4, U1.1J6, U1.B18, U1.R3, U1.R4, U1.T3, U3.A9, U3.B8, U3.C6, U3.C7, U3.E6, U3.F5, U3.J10, U3.K9, U3.M4, U3.N4, U3.P3, U3.P5, U4.31, U4.42, X1.4
PMIC_VOUT4_3V3: C50.1, L4.2, U4.27
PMIC_VREF_DDR: C8.1, C36.1, C37.1, C55.1, U1.AC20, U2.H1, U2.M8, U4.16
PMIC_WAKEUP: U1.K2, U4.2
POWER_ON: U1.R2, U4.44
SDMMC2_CK: R45.2, U1.C9, U3.K1, U3.K2, U3.K3, U3.M6
SDMMC2_CMD: R44.2, U1.A10, U3.L1, U3.L2, U3.L3, U3.M5
SDMMC2_D0: R36.2, U1.C13, U3.A3
SDMMC2_D1: R37.2, U1.B12, U3.A4
SDMMC2_D2: R38.2, U1.A11, U3.A5
SDMMC2_D3: R39.2, U1.B13, U3.A1, U3.B2
SDMMC2_D4: R40.2, U1.AB10, U3.A2, U3.B3
SDMMC2_D5: R41.2, U1.A8, U3.B4, U3.C3, U3.D2, U3.E1
SDMMC2_D6: R42.2, U1.C11, U3.B5, U3.C5, U3.D4, U3.E3, U3.F2, U3.G1
SDMMC2_D7: R43.2, U1.B11, U3.A8, U3.B6, U3.B7

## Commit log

2021-05-20 Added Project Overview Block Diagram
    [Snap Card Block Diagram.sch, snap_board.sch]
2021-05-20 Small changes
    [Top Sheet.sch, snap_board.sch]
2021-05-21 working on pmic
    [MPU Power & Reset.sch, PMIC Power.sch, Power & Reset.sch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]
2021-05-21 completed PMIC
    [Connectors.sch, MPU Power & Reset.sch, PMIC Power.sch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]
2021-05-21 added notes to pmic
    [MPU Power & Reset.sch, PMIC Power.sch]
2021-05-21 working on mpu power
    [MPU Power & Reset.sch]
2021-05-21 MPU power complete
    [Connectors.sch, MPU Power & Reset.sch, PMIC Power.sch]
2021-05-22 working on mpu
    [Connectors.sch, MPU Connectivity & Multimedia.sch, MPU Connectivity, Multimedia & Clock.sch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]
2021-05-22 MPU_1 completed
    [MPU_1.sch]
2021-05-22 working on RAM
    [Connectors.sch, MPU & DDR3L.sch, MPU Power & Reset.sch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]
2021-05-22 working on DDR
    [MPU & DDR3L.sch]
2021-05-22 minor mods on ram
    [MPU & DDR3L.sch]
2021-05-22 minor mods
    [MPU & DDR3L.sch]
2021-05-22 working on emmc
    [Connectors.sch, MPU & DDR3L.sch, MPU Power & Reset.sch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]
2021-05-23 ref designators
    [MPU & DDR3L.sch, eMMC.sch, snap_board.sch]
2021-05-23 added design documentation
    [Connectors.sch, MPU_1.sch]
2021-05-23 removed unwanted files
    [MPU Connectivity & Multimedia.sch, MPU Connectivity, Multimedia & Clock.sch, MPU Connectivity.sch]
2021-05-23 sch mods
    [Board to Board Connectors.sch, Connectors.sch, DDR3L_RAM.sch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]
2021-05-24 sch changes
    [Board to Board Connectors.sch, DDR3L_RAM.sch, STM32MP15xx_MPU.sch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]
2021-05-24 added footprints
    [Board to Board Connectors.sch, DDR3L_RAM.sch, STM32MP15xx_MPU.sch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]
2021-05-24 corrected symbol
    [Board to Board Connectors.sch]
2021-05-24 updated stm32 footprint
    [snap_board.kicad_pcb]
2021-05-24 working on bga fanout
    [DDR3L_RAM.sch, STM32MP15xx_MPU.sch, STPMIC.sch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]
2021-05-25 working on PCB
    [STPMIC.sch, snap_board.kicad_pcb]
2021-05-26 still working on RAM
    [snap_board.kicad_pcb]
2021-05-27 ram almost complete
    [snap_board.kicad_pcb]
2021-05-27 ram complete
    [snap_board.kicad_pcb]
2021-05-28 modified sch and layout
    [Board to Board Connectors.sch, STM32MP15xx_MPU.sch, snap_board.kicad_pcb]

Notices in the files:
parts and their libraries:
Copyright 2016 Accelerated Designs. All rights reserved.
